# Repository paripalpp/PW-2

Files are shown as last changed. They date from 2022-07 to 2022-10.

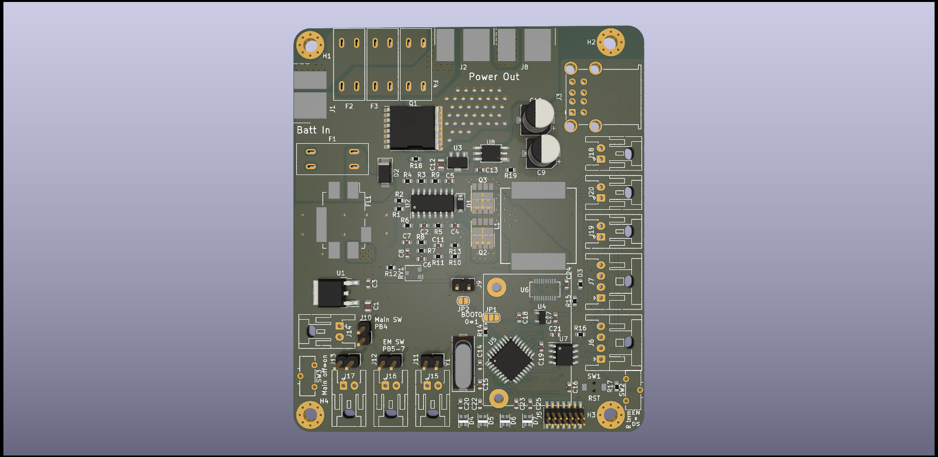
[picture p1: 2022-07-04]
PW-2.png

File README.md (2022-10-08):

# PW-2
## parts
| | |
| --- | --- |
C7								|10n
C9, C10							|100u
C6, C8, C11						|1n
C1, C12                      	|10u
C2, C3, C5, C13, C16, C19-C25	|100n
C14, C15						|22p
C4, C17, C18					|1u
D1								|D
D2								|D_TVS
D3								|LED
D4-D7							|WS2812C
F1-F4							|Fuse
FL1								|BNX022
J1								|T_conn_male
J3								|USB_A_Stacked
J5								|2x07_P1.27mm_SMD
J6, J7							|S04B-XASK-1
J2, J8							|T_conn_female
J9-J13							|PinHeader_1x02_P2.54mm
J14-J20							|S02B-XASK-1
JP1								|SolderJumper_3_Bridged12
JP2-JP6							|SolderJumper_2_Open
L1								|8.2uH
Q1								|IPT007N06N
Q2, Q3							|TPH11006NL
R1								|100k
R4, R7, R8, R11, R12			|5k
R13								|100
R2, R3, R5, R6, R9, R10, R14-R16	|10k
R17								|120
R18								|10
R19								|330
RV1								|2.2k_Potentiometer
SW1								|SW_Push
SW2, SW3						|SW_SPDT
U1								|L7812
U2								|NCP1034
U3								|L78L12_SOT89
U4								|MCP1700-3302E_SOT23
U5								|STM32F303K8Tx
U6								|IM920s
U7								|MCP2551-I-SN
U8								|TLP152
Y1								|16MHz

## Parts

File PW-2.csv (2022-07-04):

Value | Footprint
10u | 2012Metric
100n | 1608Metric
1u | 1608Metric
1n | 1608Metric
10n | 1608Metric
100u | CP_Elec_6.3x7.7
22p | 1608Metric
D | SOD-123
D_TVS | SMA
LED | 1608Metric
WS2812C | 2020Metric
Fuseholder | Keystone_3568
BNX022 | Murata_BNX025
T_conn_male | T_conn_horizontal
T_conn_female | T_conn_horizontal
USB_A_Stacked | Wuerth_61400826021
PinHeader_2x07 | P1.27mm_SMD
Conn_01x04 | XA_S04B-XASK-1
PinHeader_1x02 | P2.54mm_Vertical
Conn_01x02 | XA_S02B-XASK-1
8.2uH | Vishay_IHLP-6767
IPT007N06N | PG-HSOF-8-1
TPH11006NL | SOP_Advance
100k | 1608Metric
10k | 1608Metric
5k | 1608Metric
100 | 1608Metric
120 | 1608Metric
10 | 1608Metric
330 | 1608Metric
2.2k_Potentiometer | Murata_PVZ3A
SW_Push | TVAF06-A020B-R
SW_SPDT | IS-1245T-G
L7812 | TO-252-2
NCP1034 | SOIC-16
L78L12_SOT89 | SOT-89-3
MCP1700-3302E | SOT-23
STM32F303K8Tx | LQFP-32
IM920s | IM920s
MCP2551-I-SN | SOIC-8
TLP152 | SO-6_5pin
16MHz | HC49-SD

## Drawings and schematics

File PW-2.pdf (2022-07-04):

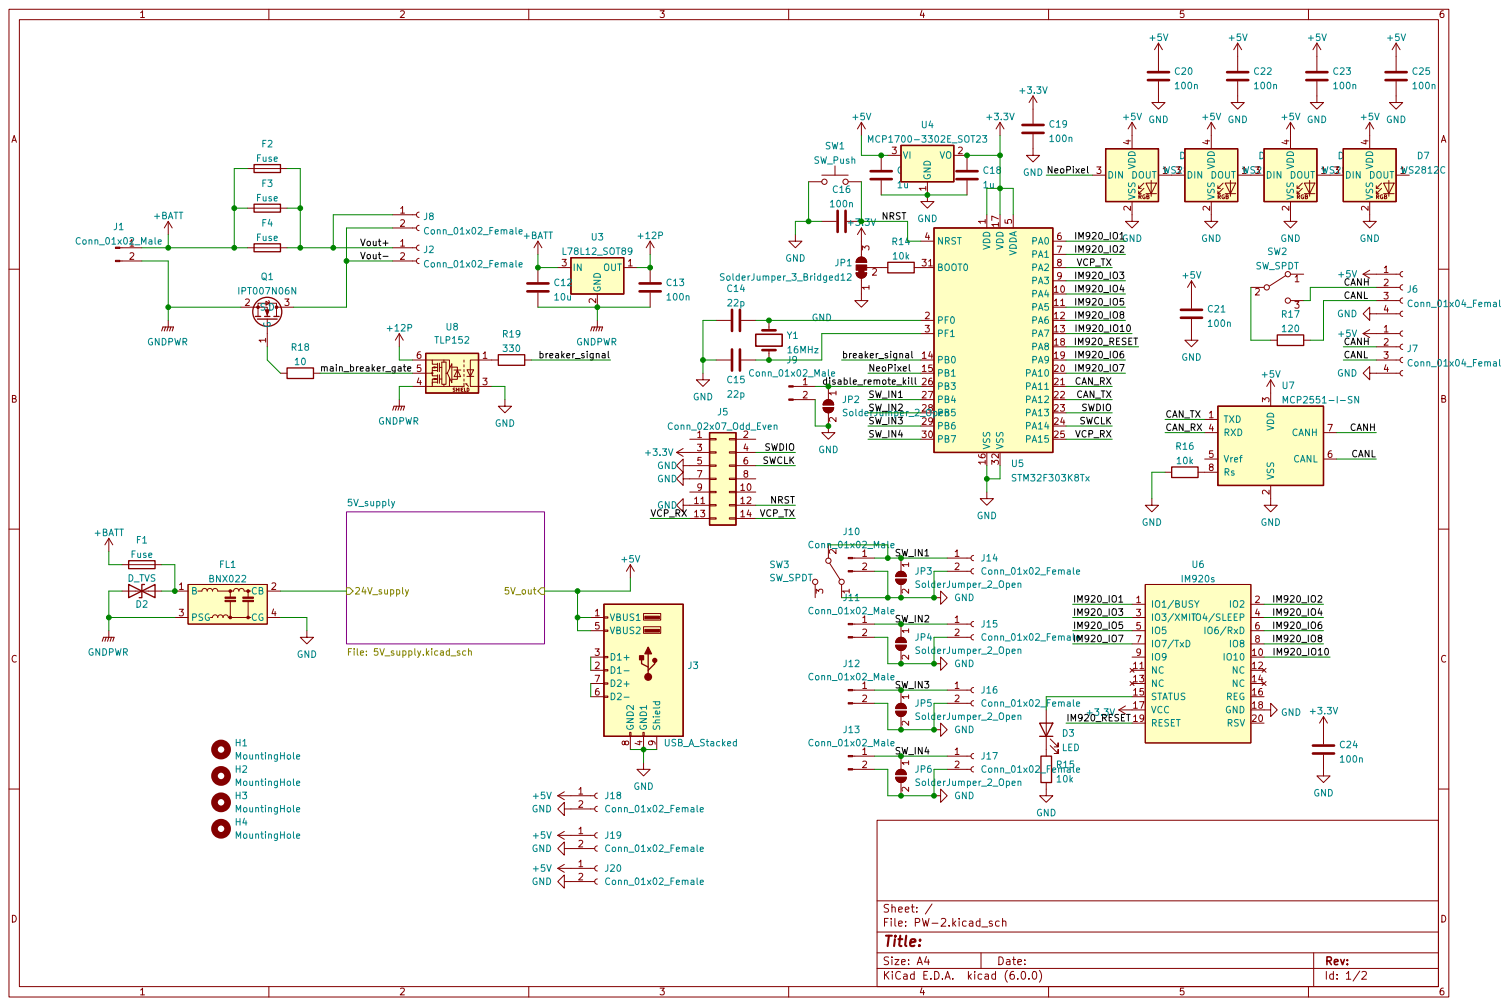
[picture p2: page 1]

1 PA4 10 PA5 11 PA6 12 PA7 13 PB0 14 PB1 15 VSS 16 VDD 17 PA8 18 PA9 19 PF0 2 PA10 20 PA11 21 PA12 22 PA13 23 PA14 24 PA15 25 PB3 26 PB4 27 PB5 28 PB6 29 PF1 3 PB7 30 BOOT0 31 VSS 32 NRST 4 VDDA

3 RXD 4 Vref 5 CANL 6 CANH 7 Rs 8 U7MCP2551-I-SN

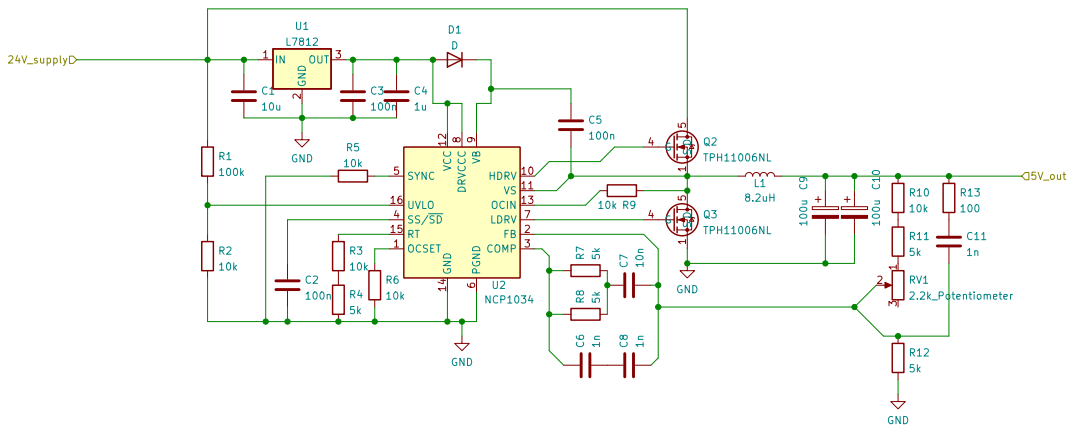
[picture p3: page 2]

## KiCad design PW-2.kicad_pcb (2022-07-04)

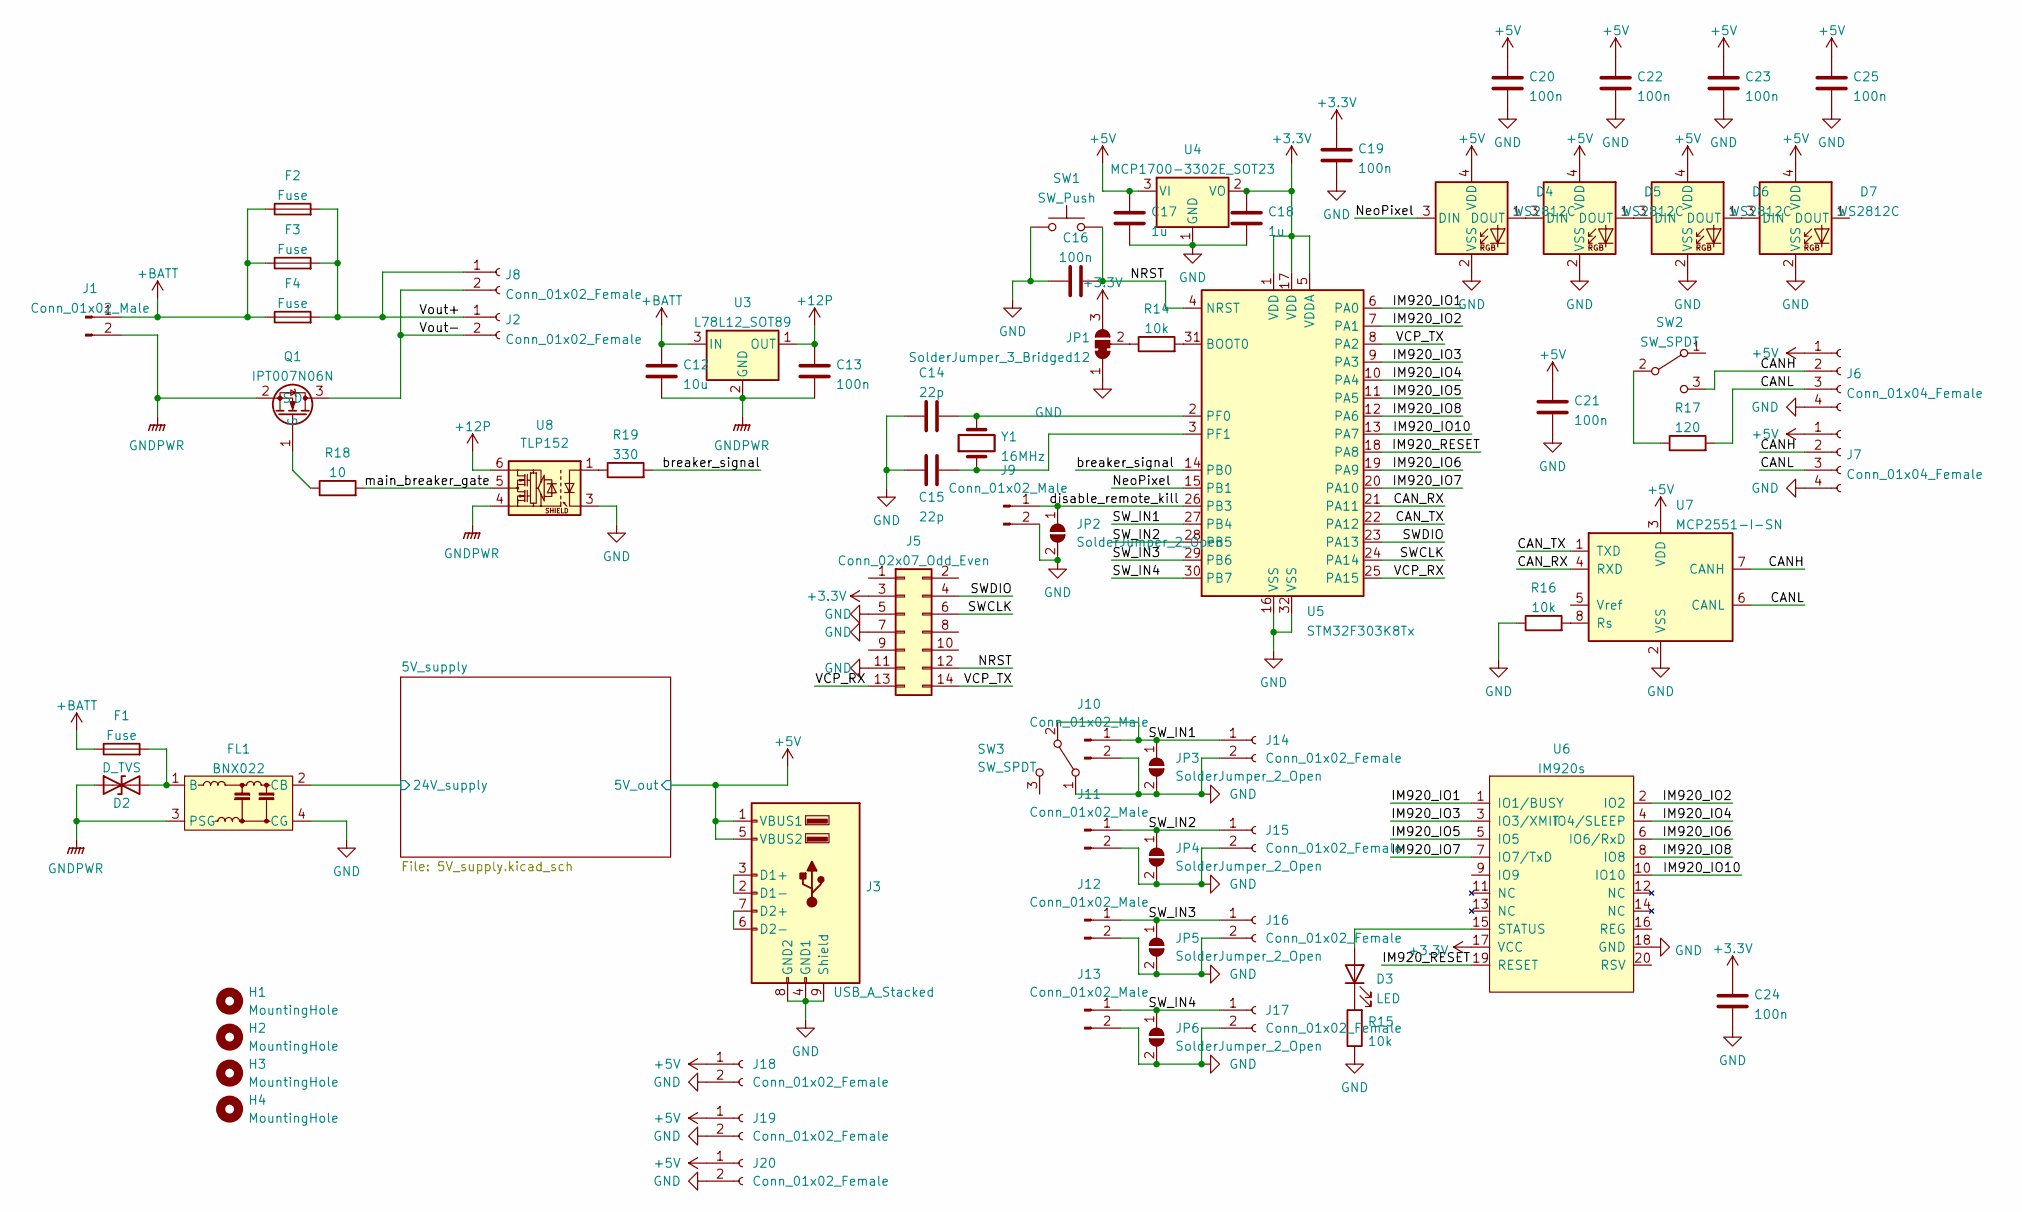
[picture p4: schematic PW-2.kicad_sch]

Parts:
C12: 10u; C_0805_2012Metric
C13, C16, C19, C20, C21, C22, C23, C24, C25: 100n; C_0603_1608Metric
C14, C15: 22p; C_0603_1608Metric
C17, C18: 1u; C_0603_1608Metric
D2: D_TVS; D_SMA
D3: LED; R_0603_1608Metric
D4, D5, D6, D7: WS2812C; LED_2020Metric_WS2812C_2.0x2.0mm_P1.0mm
F1, F2, F3, F4: Fuse; Fuseholder_Keystone_3568
FL1: BNX022; Filter_Murata_BNX025_ThermalVias
H1, H2, H3, H4: MountingHole; MountingHole_3.2mm_M3_Pad_Via
J1: Conn_01x02_Male; T_connecter_male_horizontal
J2, J8: Conn_01x02_Female; T_connecter_female_horizontal
J3: USB_A_Stacked; USB_A_Wuerth_61400826021_Horizontal_Stacked
J5: Conn_02x07_Odd_Even; PinHeader_2x07_P1.27mm_Vertical_SMD
J6, J7: Conn_01x04_Female; JST_XA_S04B-XASK-1_1x04_P2.50mm_Horizontal
J9, J10, J11, J12, J13: Conn_01x02_Male; PinHeader_1x02_P2.54mm_Vertical
J14, J15, J16, J17, J18, J19, J20: Conn_01x02_Female; JST_XA_S02B-XASK-1_1x02_P2.50mm_Horizontal
JP1: SolderJumper_3_Bridged12; SolderJumper-3_P1.3mm_Bridged12_RoundedPad1.0x1.5mm
JP2, JP3, JP4, JP5, JP6: SolderJumper_2_Open; SolderJumper-2_P1.3mm_Open_RoundedPad1.0x1.5mm
Q1: IPT007N06N; Infineon_PG-HSOF-8-1
R14, R15, R16: 10k; R_0603_1608Metric
R17: 120; R_0603_1608Metric
R18: 10; R_0603_1608Metric
R19: 330; R_0603_1608Metric
SW1: SW_Push; TVAF06-A020B-R
SW2, SW3: SW_SPDT; IS-1245T-G
U3: L78L12_SOT89; SOT-89-3
U4: MCP1700-3302E_SOT23; SOT-23
U5: STM32F303K8Tx; LQFP-32_7x7mm_P0.8mm
U6: IM920s
U7: MCP2551-I-SN; SOIC-8_3.9x4.9mm_P1.27mm
U8: TLP152; SO-6_5pin_4.4x3.6mm_P1.27mm
Y1: 16MHz; Crystal_SMD_HC49-SD

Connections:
+3V3: C18.2, C19.2, C24.2, J5.3, JP1.3 (B), U4.2 (VO), U5.1 (VDD), U5.5 (VDDA), U5.17 (VDD), U6.17 (VCC)
+5V: C17.2, C20.2, C21.2, C22.2, C23.2, C25.2, D4.4 (VDD), D5.4 (VDD), D6.4 (VDD), D7.4 (VDD), J3.1 (VBUS1), J3.5 (VBUS2), J6.1, J7.1, J18.1, J19.1, J20.1, U4.3 (VI), U7.3 (VDD); also elsewhere on the board
+12P: C13.2, U3.1 (OUT), U8.6
+BATT: C12.1, F1.1, F2.1, F3.1, F4.1, J1.1, U3.3 (IN)
/5V_supply/24V_supply: FL1.2 (CB); also elsewhere on the board
/CANH: J6.2, J7.2, SW2.3 (C), U7.7 (CANH)
/CANL: J6.3, J7.3, R17.2, U7.6 (CANL)
/CAN_RX: U5.21 (PA11), U7.4 (RXD)
/CAN_TX: U5.22 (PA12), U7.1 (TXD)
/IM920_IO1: U5.6 (PA0), U6.1 (IO1/BUSY)
/IM920_IO2: U5.7 (PA1), U6.2 (IO2)
/IM920_IO3: U5.9 (PA3), U6.3 (IO3/XMIT)
/IM920_IO4: U5.10 (PA4), U6.4 (IO4/SLEEP)
/IM920_IO5: U5.11 (PA5), U6.5 (IO5)
/IM920_IO6: U5.19 (PA9), U6.6 (IO6/RxD)
/IM920_IO7: U5.20 (PA10), U6.7 (IO7/TxD)
/IM920_IO8: U5.12 (PA6), U6.8 (IO8)
/IM920_IO10: U5.13 (PA7), U6.10 (IO10)
/IM920_RESET: U5.18 (PA8), U6.19 (RESET)
/NRST: C16.2, J5.12, SW1.2, U5.4 (NRST)
/NeoPixel: D4.3 (DIN), U5.15 (PB1)
/SWCLK: J5.6, U5.24 (PA14)
/SWDIO: J5.4, U5.23 (PA13)
/SW_IN1: J10.1, J14.1, JP3.1 (A), SW3.2 (B), U5.27 (PB4)
/SW_IN2: J11.1, J15.1, JP4.1 (A), U5.28 (PB5)
/SW_IN3: J12.1, J16.1, JP5.1 (A), U5.29 (PB6)
/SW_IN4: J13.1, J17.1, JP6.1 (A), U5.30 (PB7)
/VCP_RX: J5.13, U5.25 (PA15)
/VCP_TX: J5.14, U5.8 (PA2)
/Vout+: F2.2, F3.2, F4.2, J2.1, J8.1
/Vout-: J2.2, J8.2, Q1.3 (D)
/breaker_signal: R19.2, U5.14 (PB0)
/disable_remote_kill: J9.1, JP2.1 (A), U5.26 (PB3)
/main_breaker_gate: R18.2, U8.5
GND: C14.1, C15.1, C16.1, C17.1, C18.1, C19.1, C20.1, C21.1, C22.1, C23.1, C24.1, C25.1, D4.2 (VSS), D5.2 (VSS), D6.2 (VSS), D7.2 (VSS), FL1.4 (CG), J3.4 (GND1), J3.8 (GND2), J3.9 (Shield), J5.5, J5.7, J5.11, J6.4, J7.4, J9.2, J10.2, J11.2, J12.2, J13.2, J14.2, J15.2, J16.2, J17.2, J18.2, J19.2, J20.2, JP1.1 (A), JP2.2 (B), JP3.2 (B), JP4.2 (B), JP5.2 (B), JP6.2 (B), R15.1, R16.1, SW1.1, SW3.1 (A), U4.1 (GND), U5.16 (VSS), U5.32 (VSS), U6.18 (GND), U7.2 (VSS), U8.3; also elsewhere on the board
GNDPWR: C12.2, C13.1, D2.1 (A1), FL1.3 (PSG), J1.2, Q1.2 (S), U3.2 (GND), U8.4
unnamed: C14.2, U5.2 (PF0), Y1.2
unnamed: C15.2, U5.3 (PF1), Y1.1
unnamed: D2.2 (A2), F1.2, FL1.1 (B)
unnamed: D3.1 (K), R15.2
unnamed: D3.2 (A), U6.15 (STATUS)
unnamed: D4.1 (DOUT), D5.3 (DIN)
unnamed: D5.1 (DOUT), D6.3 (DIN)
unnamed: D6.1 (DOUT), D7.3 (DIN)
unnamed: J3.2 (D1-), J3.3 (D1+)
unnamed: J3.6 (D2-), J3.7 (D2+)
unnamed: JP1.2 (C), R14.1
unnamed: Q1.1 (G), R18.1
unnamed: R14.2, U5.31 (BOOT0)
unnamed: R16.2, U7.8 (Rs)
unnamed: R17.1, SW2.2 (B)
unnamed: R19.1, U8.1

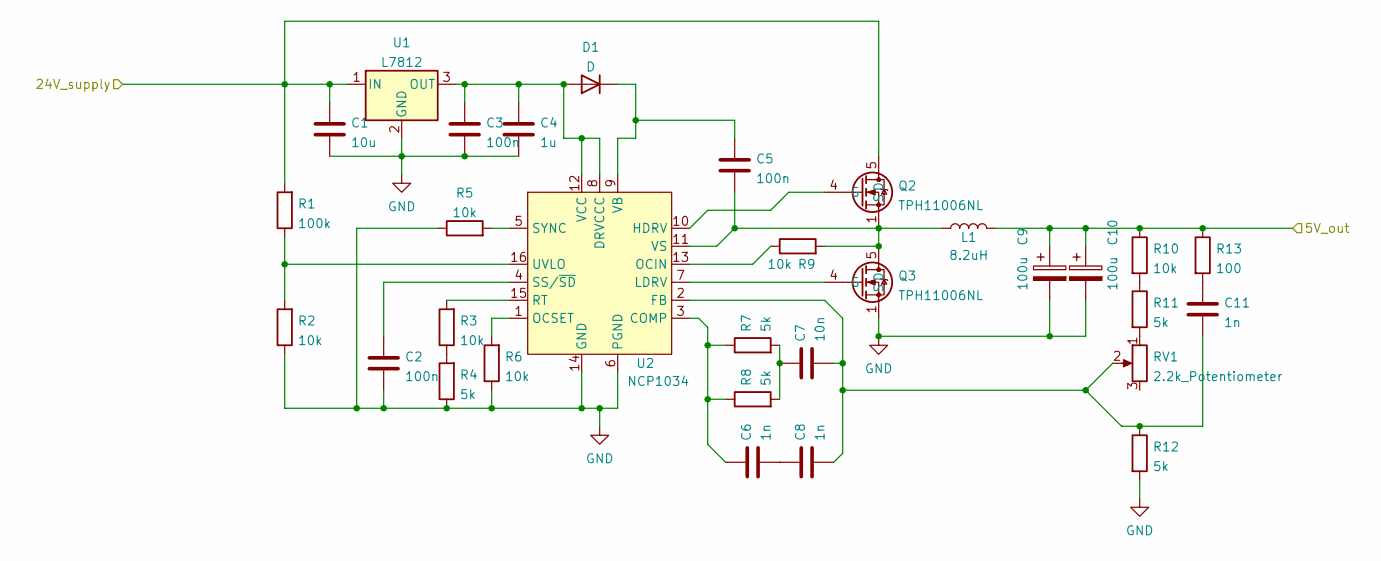
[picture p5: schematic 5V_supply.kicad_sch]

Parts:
C1: 10u; C_0805_2012Metric
C2, C3, C5: 100n; C_0603_1608Metric
C4: 1u; C_0603_1608Metric
C6, C8, C11: 1n; C_0603_1608Metric
C7: 10n; C_0603_1608Metric
C9, C10: 100u; CP_Elec_6.3x7.7
D1: D; D_SOD-123
L1: 8.2uH; L_Vishay_IHLP-6767
Q2, Q3: TPH11006NL; Toshiba_SOP_Advance
R1: 100k; R_0603_1608Metric
R2, R3, R5, R6, R9, R10: 10k; R_0603_1608Metric
R4, R7, R8, R11, R12: 5k; R_0603_1608Metric
R13: 100; R_0603_1608Metric
RV1: 2.2k_Potentiometer; Potentiometer_Murata_PVZ3A
U1: L7812; TO-252-2
U2: NCP1034; SOIC-16_3.9x9.9mm_P1.27mm

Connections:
+5V: C9.1, C10.1, L1.2, R10.1, R13.1; also elsewhere on the board
/5V_supply/24V_supply: C1.1, Q2.5 (D), Q2.6 (D), Q2.7 (D), Q2.8 (D), R1.2, U1.1 (IN); also elsewhere on the board
GND: C1.2, C2.2, C3.2, C4.2, C9.2, C10.2, Q3.1 (S), Q3.2 (S), Q3.3 (S), R2.1, R4.1, R5.1, R6.1, R12.2, U1.2 (GND), U2.6 (PGND), U2.14 (GND); also elsewhere on the board
unnamed: C2.1, U2.4 (SS/~SD)
unnamed: C3.1, C4.1, D1.2 (A), U1.3 (OUT), U2.8 (DRVCCC), U2.12 (VCC)
unnamed: C5.1, D1.1 (K), U2.9 (VB)
unnamed: C5.2, L1.1, Q2.1 (S), Q2.2 (S), Q2.3 (S), Q3.5 (D), Q3.6 (D), Q3.7 (D), Q3.8 (D), R9.2, U2.11 (VS)
unnamed: C6.1, R7.1, R8.1, U2.3 (COMP)
unnamed: C6.2, C8.1
unnamed: C7.2, R7.2, R8.2
unnamed: C11.1, R13.2
unnamed: C7.1, C8.2, C11.2, R12.1, RV1.2, U2.2 (FB)
unnamed: Q2.4 (G), U2.10 (HDRV)
unnamed: Q3.4 (G), U2.7 (LDRV)
unnamed: R1.1, R2.2, U2.16 (UVLO)
unnamed: R3.1, R4.2
unnamed: R3.2, U2.15 (RT)
unnamed: R5.2, U2.5 (SYNC)
unnamed: R6.2, U2.1 (OCSET)
unnamed: R9.1, U2.13 (OCIN)
unnamed: R10.2, R11.1
unnamed: R11.2, RV1.1

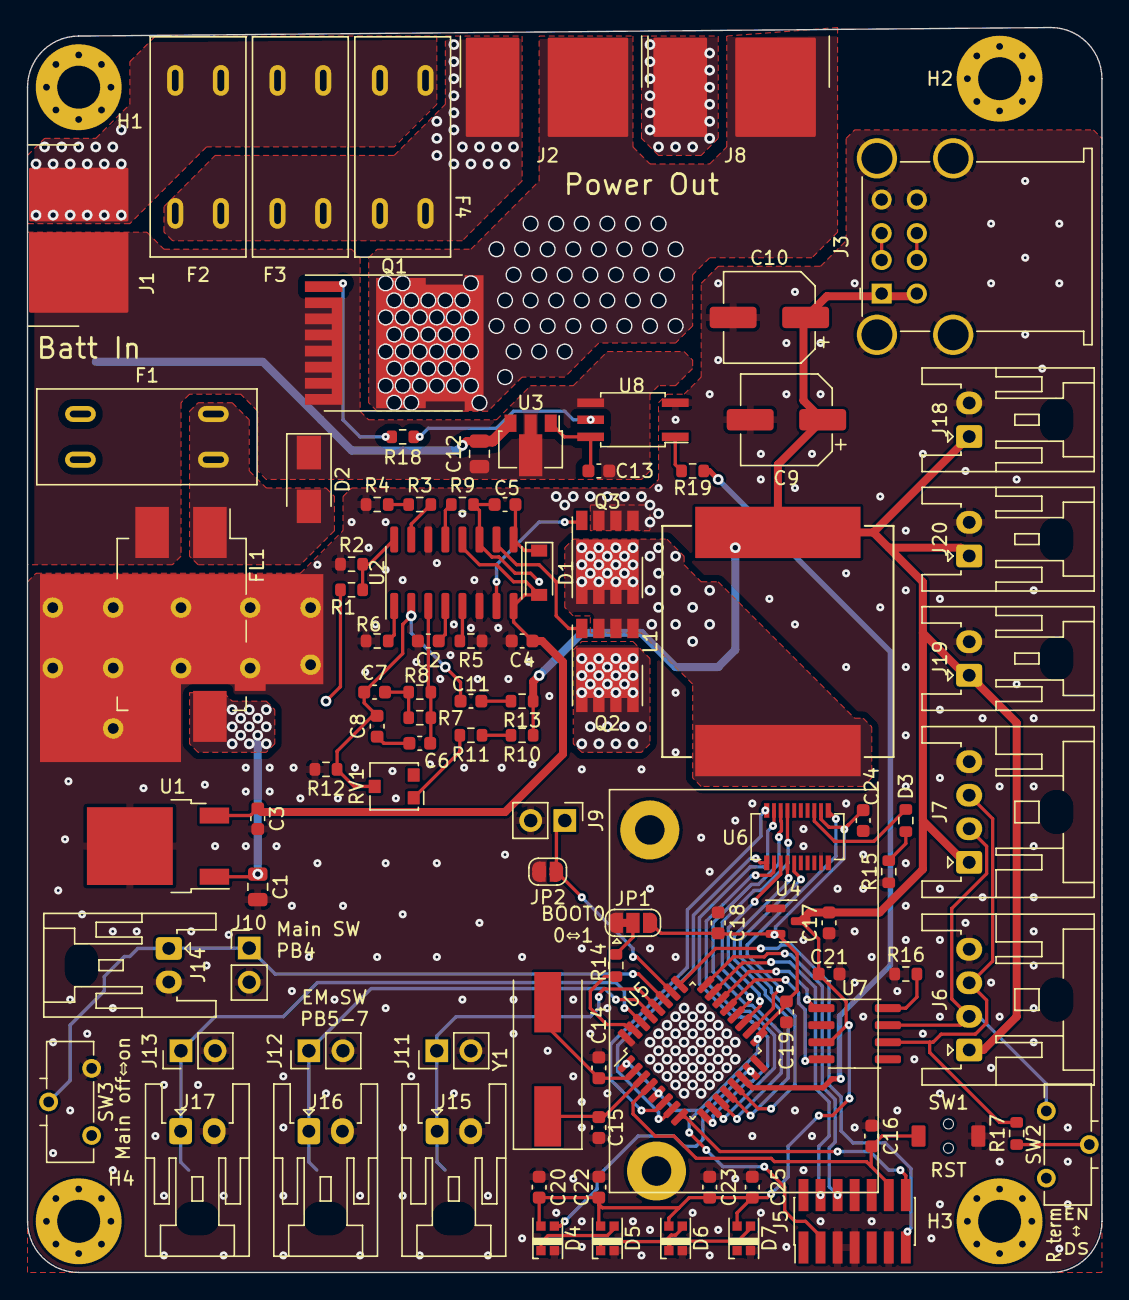
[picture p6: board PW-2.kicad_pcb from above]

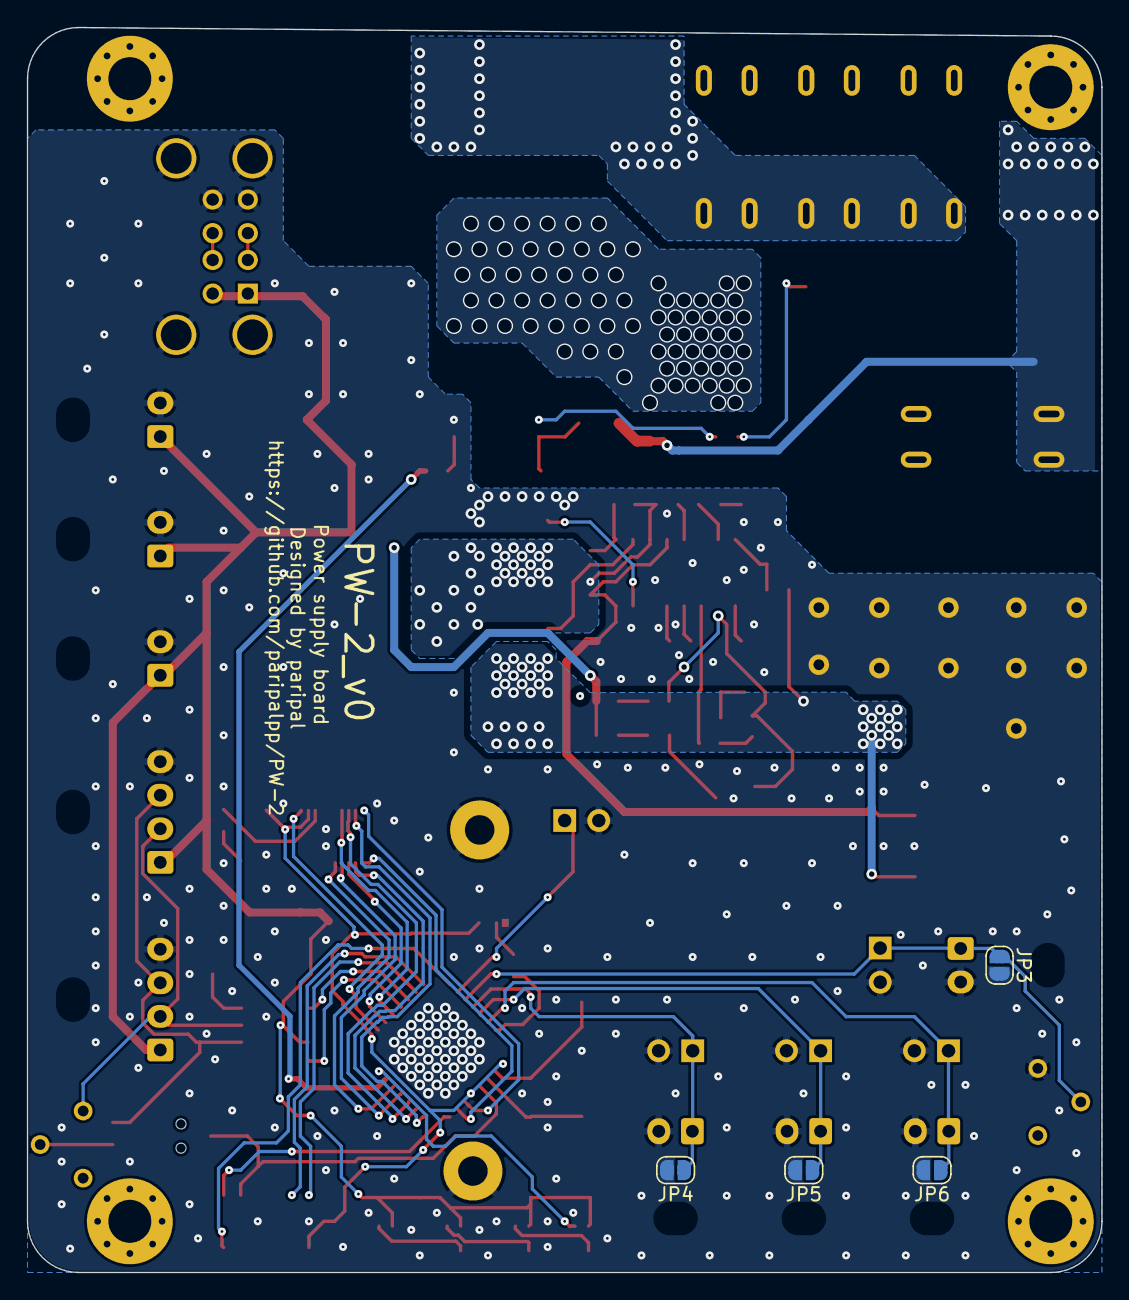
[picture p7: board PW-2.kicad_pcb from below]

Board: 2 copper layers, 80.0 x 92.7 mm, 102 parts (4 on the bottom side), 71 nets.

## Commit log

2022-05-11 separate to some sheets
    [12-19V_supply.kicad_sch, 5V_supply.kicad_sch, PW-2.kicad_sch]
2022-05-13 little change
    [12-19V_supply.kicad_sch, 5V_supply.kicad_sch, PW-2.kicad_sch]
2022-06-22 DC-DC pram setted
    [12-19V_supply.kicad_sch, 5V_supply.kicad_sch, PW-2.kicad_sch]
2022-07-04 drawing around power done
    [PW-2.kicad_pcb, PW-2.kicad_sch]
2022-07-04 v0 done!
    [PW-2.csv, PW-2.kicad_pcb, PW-2.kicad_sch]
